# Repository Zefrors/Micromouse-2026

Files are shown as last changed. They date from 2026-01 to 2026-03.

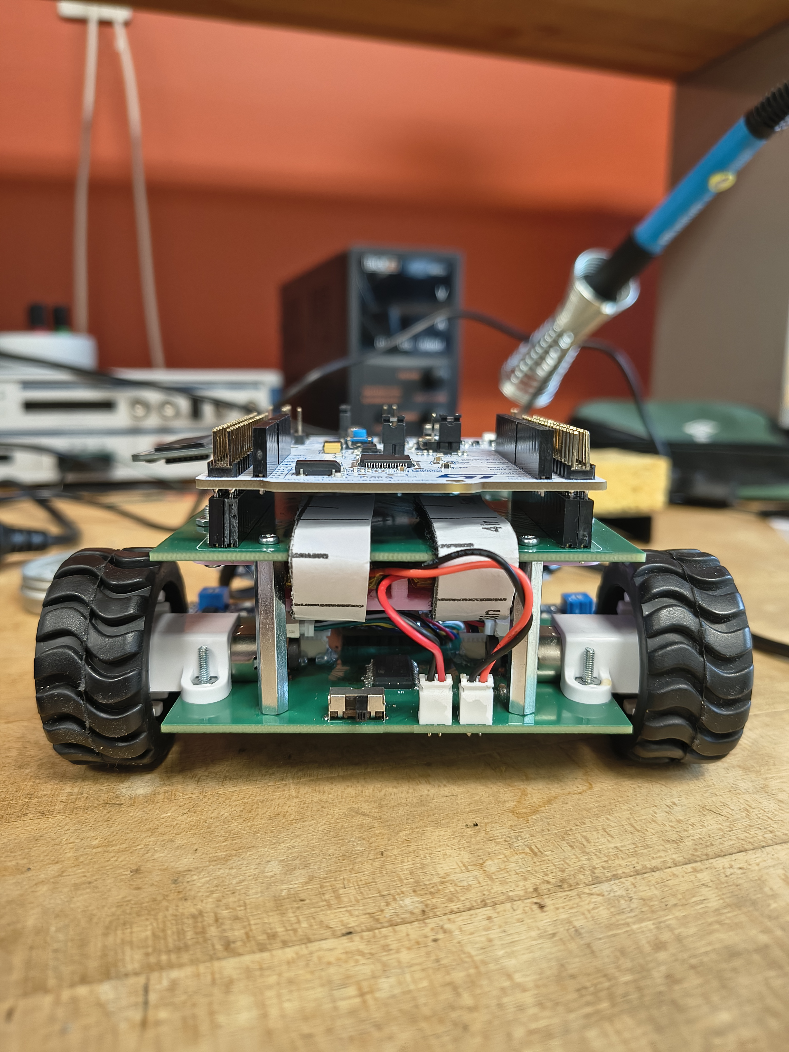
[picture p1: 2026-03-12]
pic/IMG_20260312_125618599_HDR.jpg

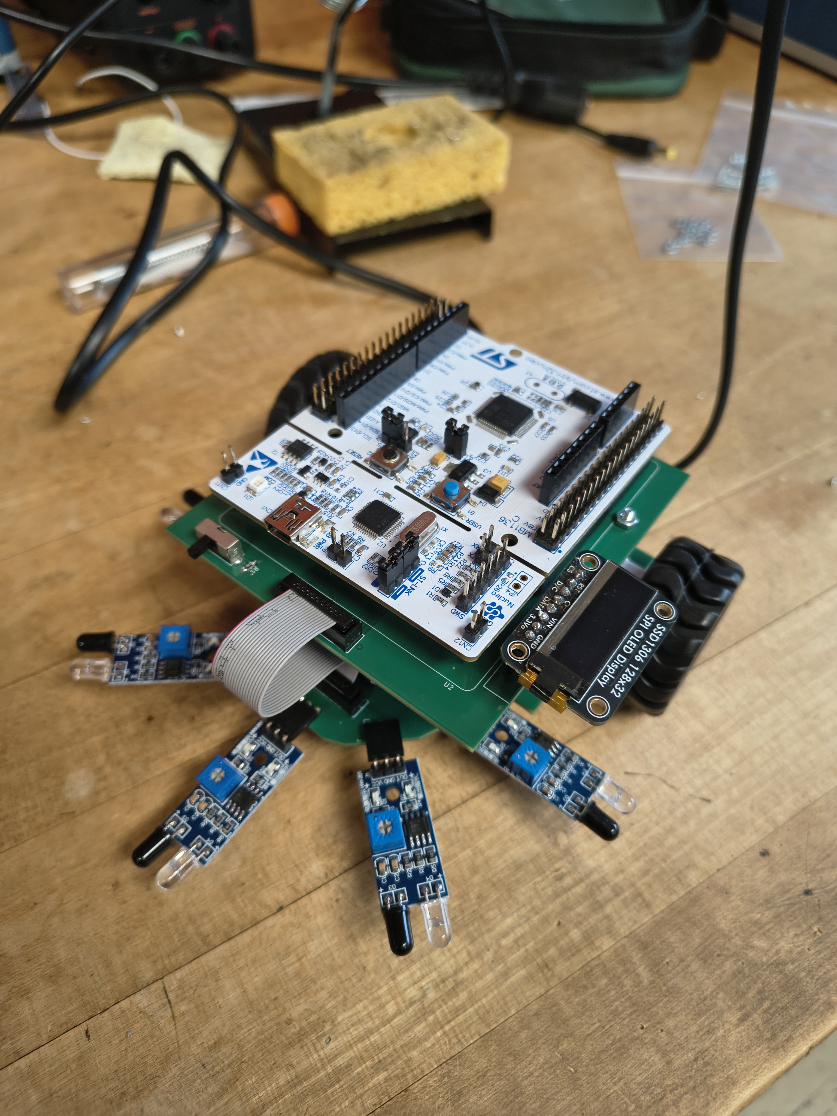
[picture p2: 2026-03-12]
pic/IMG_20260312_125603022_HDR.jpg

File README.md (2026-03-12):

# Temple IEEE Micromouse 2026
Competing at IEEE SAC R1 & R2! https://attend.ieee.org/sac-2026/ on 3/20/26

IMG_20260312_125613744_HDR
IMG_20260312_125603022_HDR
IMG_20260312_125618599_HDR

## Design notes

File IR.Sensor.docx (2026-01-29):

IR Sensor and Module

IR Sensor Module | How IR Sensor Module Works » ElectroDuino (https://www.electroduino.com/what-is-ir-sensor-module-how-ir-sensor-module-works/)

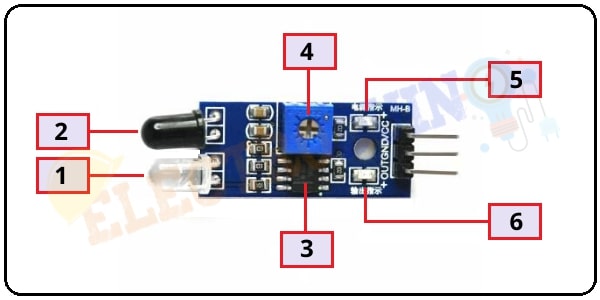
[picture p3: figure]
IR-Sensor-Module-Hardware-Overview IR Sensor Module | How IR Sensor Module Works

1. Infrared LED or IR Transmitter:

2. Photodiode Receiver or IR Receiver:

4. Variable Resistor (Trim pot)

- This variable resistor is a 10k preset. It is used to set the range of operation. Rotate the preset knob to adjust the detection distance, the effective operation range 2-10 cm. If the preset knob rotated clockwise, the detection range will be increased. If it rotated counterclockwise, the detection range will be decreased.

- Could be used for long/short distance reading

- IE When short distance sensor goes off we know the wall is close

5. Power LED:

- LED that indicates the IR Sensor power supply is on or off

6. Output LED:

- When infrared reflected back to the IR receiver and the sensor detects an obstacle, the green LED lights up. So, the Green LED use to indicate the sensor senses an obstacle.

Circuit

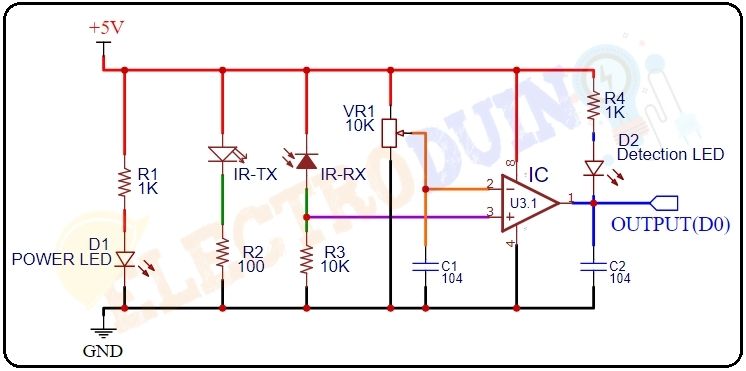
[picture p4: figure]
How-to-make-IR-Sensor-Module-Circuit-Diagram IR Sensor Module | How IR Sensor Module Works

Buy Link (https://www.amazon.com/EC-Buying-Infrared-Obstacle-Avoidance/dp/B0CWKWWKYL?adgrpid=1330409636736144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)

Intensity = 1/d^2

Calibration

Way to protect sensors if crash happens

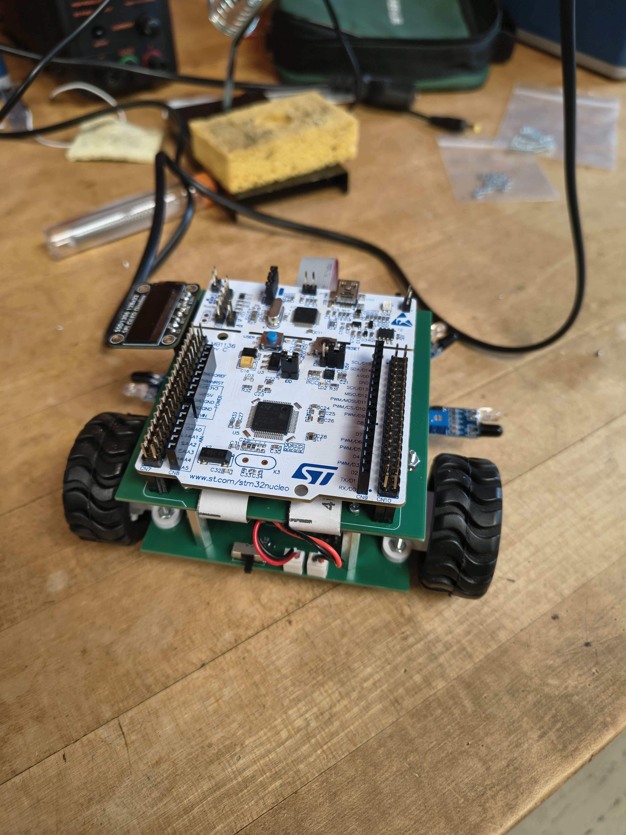
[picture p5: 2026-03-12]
pic/IMG_20260312_125607477_HDR.jpg

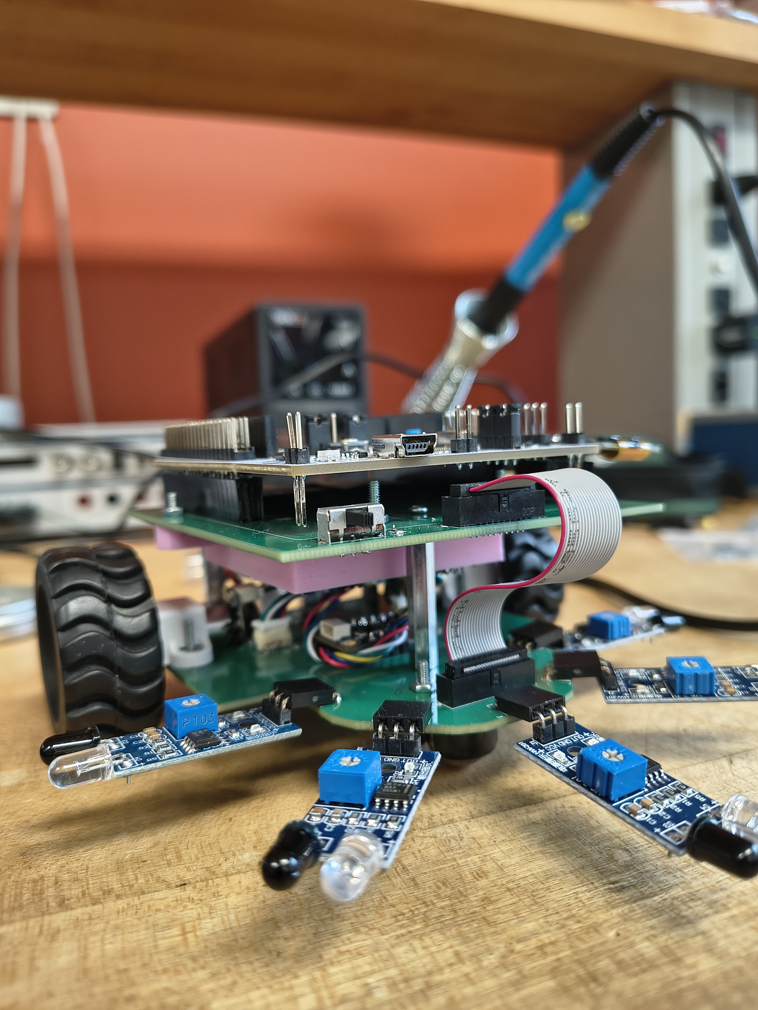
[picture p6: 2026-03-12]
pic/IMG_20260312_125613744_HDR.jpg

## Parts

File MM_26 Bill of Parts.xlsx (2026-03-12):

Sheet: Sheet1
Part | Quantity | Quantity Extra | Unit Price | Part Number | Link | Description | Total Price | URL
Motor | 2 |  | $20.95 | 2378 | https://www.pololu.com/product/2378 | Small brushed motor | $41.90 | https://www.pololu.com/product/2378
Motor Encoder Pair | 1 |  | $7.95 | 4760 | https://www.pololu.com/product/4760 | Encoder pair for motors ; connect at back | $7.95 | https://www.pololu.com/product/4760
Wheels | 1 |  | $8.95 | 1090 | https://www.pololu.com/product/1090 | attach to motor bracket | $8.95 | https://www.pololu.com/product/1090
IR Sensor Module | 5 | 5 | $0.88 |  | https://amazon.com/dp/B07W97H2WS |  | $8.79 | https://amazon.com/dp/B07W97H2WS
Dual H-Bridge | 1 |  | $7.69 | 497-1390-5-ND | https://www.digikey.com/en/products/detail/stmicroelectronics/L293DD/585913 | IC dual-H bridge | $7.69 | https://www.digikey.com/en/products/detail/stmicroelectronics/L293DD/585913
IMU | 1 |  | $19.95 | 4502 | https://www.adafruit.com/product/4502 | Gryo + Accel | $19.95 | https://www.adafruit.com/product/4502
STM32 Nucleo L476RG | 1 |  | $14.53 |  | https://www.st.com/en/evaluation-tools/nucleo-l476rg.html#st_all-features_sec-nav-tab | STM32 Nucleo Board | $14.53 | https://www.st.com/en/evaluation-tools/nucleo-l476rg.html#st_all-features_sec-nav-tab
Caster Wheel |  | Decide based on height |  |  |  |  |  | https://www.pololu.com/category/45/pololu-ball-casters
OLED Screen | 1 |  | $17.50 | 661 | https://www.adafruit.com/product/661 | Display |  | https://www.adafruit.com/product/661
Voltage Regulator | 1 |  | $0.24 | AZ1117IH-3.3TRG1DICT-ND | https://www.digikey.com/en/products/detail/diodes-incorporated/AZ1117IH-3-3TRG1/5699672 | 3V3 LDO Regulator |  | https://www.digikey.com/en/products/detail/diodes-incorporated/AZ1117IH-3-3TRG1/5699672
Battery Connector | 2 |  | $0.10 | 455-1704-ND | https://www.digikey.com/en/products/detail/jst-sales-america-inc/B2B-PH-K-S-LF-SN/926611 | 2mm JST Connector |  | https://www.digikey.com/en/products/detail/jst-sales-america-inc/B2B-PH-K-S-LF-SN/926611
Slide Switch | 2 | 1 | $0.72 | EG1906-ND | https://www.digikey.com/en/products/detail/e-switch/EG1213/101735 | Switch |  | https://www.digikey.com/en/products/detail/e-switch/EG1213/101735
JST SH Connector | 2 |  | $0.67 | 455-BM06B-SRSS-TBCT-ND | www.digikey.com/en/products/detail/jst-sales-america-inc/BM06B-SRSS-TB/926698 | Motor to Board |  | www.digikey.com/en/products/detail/jst-sales-america-inc/BM06B-SRSS-TB/926698
Motor Cable | Decide Length |  |  |  |  |  |  | https://www.pololu.com/category/277/6-pin-jst-sh-style-cables-for-micro-metal-gearmotor-encoders
Right Angle Pin Header | 5 |  | $0.52 | 2703 |  | For IR Sensor Module |  | https://www.pololu.com/product/2703
Motor Bracket | 1 |  | $4.95 | 1089 | https://www.pololu.com/category/161/brackets-for-micro-metal-gearmotors
Resistor | 1 | 9 | $0.01 |  | https://www.digikey.com/en/products/detail/yageo/RC0805JR-0710KL/728241
100nF |  |  |  | 399-C0805C104K5RACTUCT-ND | https://www.digikey.com/en/products/detail/kemet/C0805C104K5RACTU/411169
4.7uF |  |  |  | 1276-1244-1-ND | https://www.digikey.com/en/products/detail/samsung-electro-mechanics/CL21A475KAQNNNE/3886902
10uF |  |  |  | 1276-2872-1-ND | https://www.digikey.com/en/products/detail/samsung-electro-mechanics/CL21B106KOQNNNE/3888530
22uF |  |  |  | 1276-CL21A226MAYNNNECT-ND | https://www.digikey.com/en/products/detail/samsung-electro-mechanics/CL21A226MAYNNNE/10479857
IDC Cable Header |  |  |  |  | https://www.digikey.com/en/products/detail/cnc-tech/3220-20-0100-00/3883663
Cable Short |  |  |  |  | https://www.digikey.com/en/products/detail/samtec-inc/FFSD-10-D-02-00-01-N/1106582
Cable Long |  |  |  |  | https://www.digikey.com/en/products/detail/samtec-inc/FFSD-10-D-03-00-01-N/2651117

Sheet: receipts
 | Cost | Receipt | Description
DIGIKEY 1 | 50.08 |  | Materials to connect top and bottom board
DIGIKEY 2 | 38.56 |  | Parts on boards
ADAFRUIT | 55.93 |  | Gyroscope + OLED
JLC | 71.43 |  | PCBs
POLOLU | 113.18 |  | Motors, Mechanical Assembly Parts
AMAZON | 19.9 |  | Batteries
TOTAL | 349.08

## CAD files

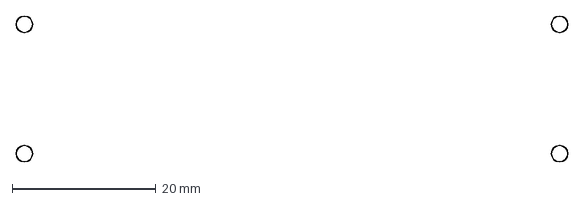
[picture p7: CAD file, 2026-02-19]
MM26/edge_cuts/mm26_bottom_motor_holes.dxf
76.8 x 20.3 mm

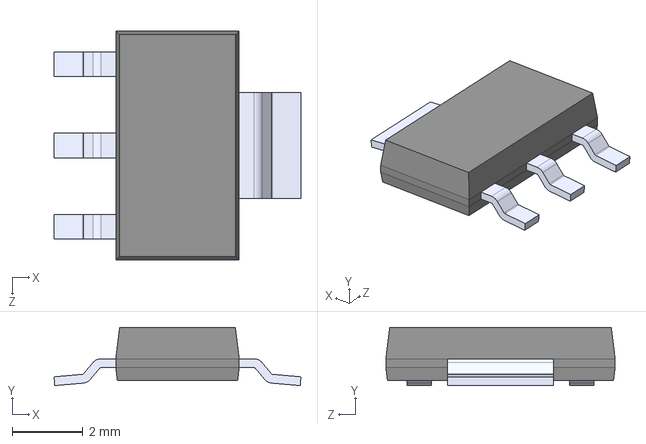
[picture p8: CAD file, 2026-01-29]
MM26/parts/AZ1117IH_3_3TRG1/AZ1117IH-3.3TRG1.step
7.00 x 1.65 x 6.50 mm

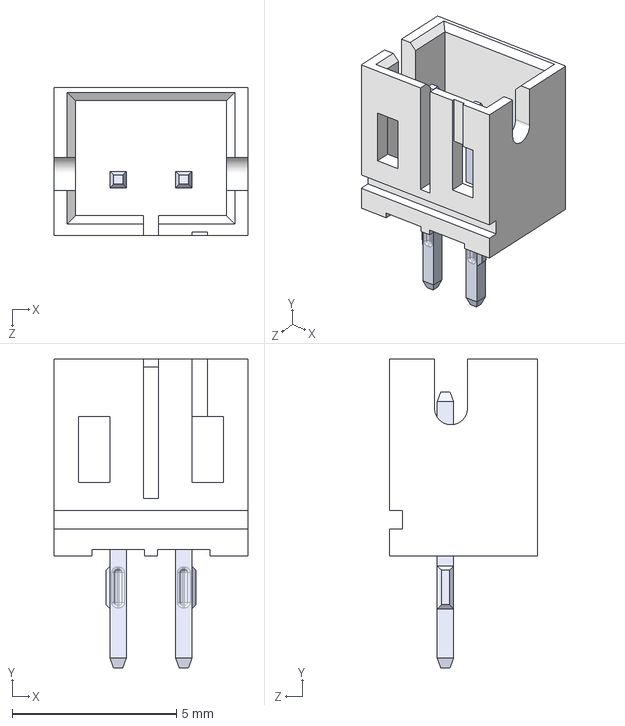
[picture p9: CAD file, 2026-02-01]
MM26/parts/B2B_PH_K_S/B2B-PH-K-S.step
5.90 x 9.40 x 4.50 mm

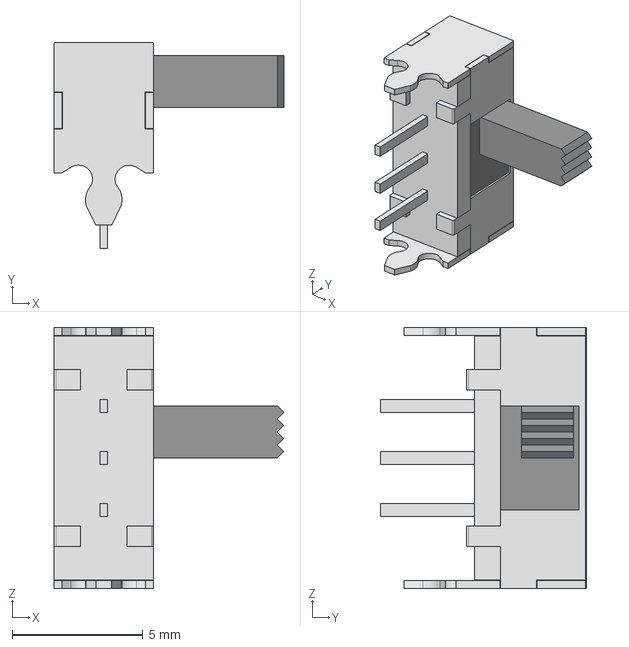
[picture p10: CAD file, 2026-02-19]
MM26/parts/EG1213/EG1213.step
8.80 x 7.90 x 10.00 mm

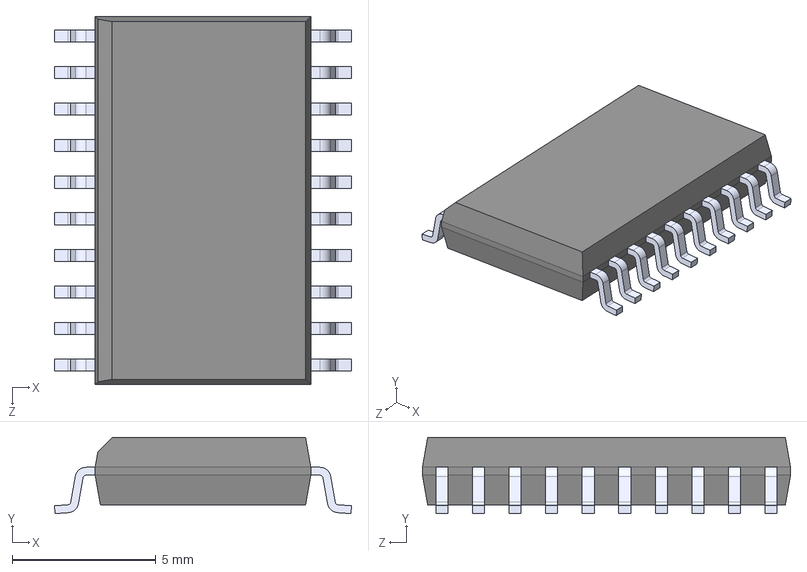
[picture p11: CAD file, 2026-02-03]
MM26/parts/L293DD/L293DD.step
10.3 x 2.65 x 12.8 mm

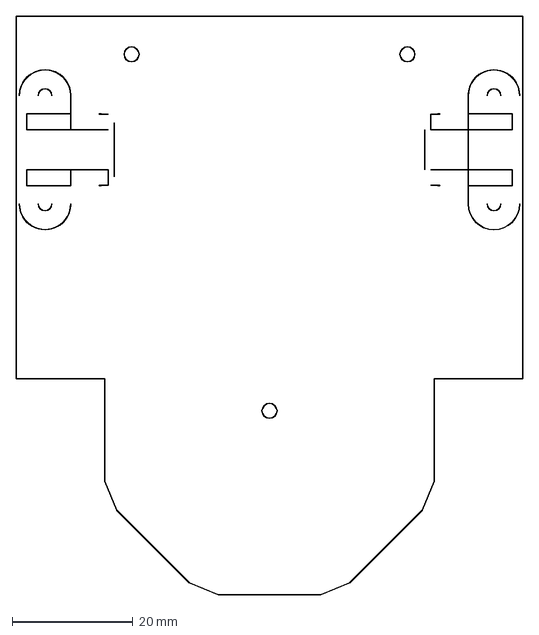
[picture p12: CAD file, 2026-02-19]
MM26/edge_cuts/mm26_bottom_motor.dxf
84.0 x 96.0 mm

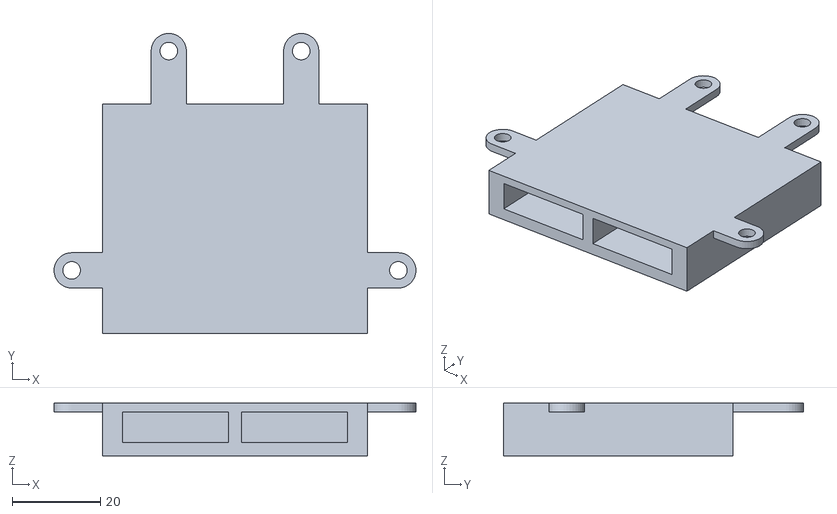
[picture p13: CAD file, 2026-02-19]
MM26/edge_cuts/mm26_horizontal_holder.stl
82.0 x 68.0 x 12.0

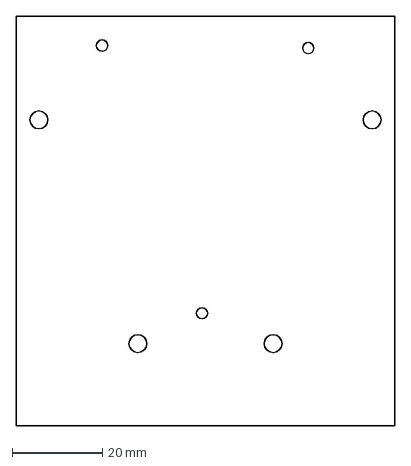
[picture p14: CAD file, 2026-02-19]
MM26/edge_cuts/mm26_top.dxf
84.0 x 91.0 mm

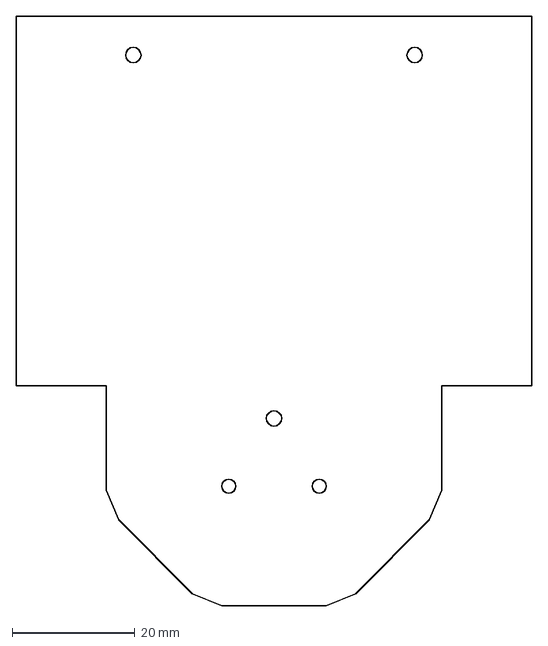
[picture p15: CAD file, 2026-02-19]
MM26/edge_cuts/bottom_no_motor.dxf
84.0 x 96.0 mm

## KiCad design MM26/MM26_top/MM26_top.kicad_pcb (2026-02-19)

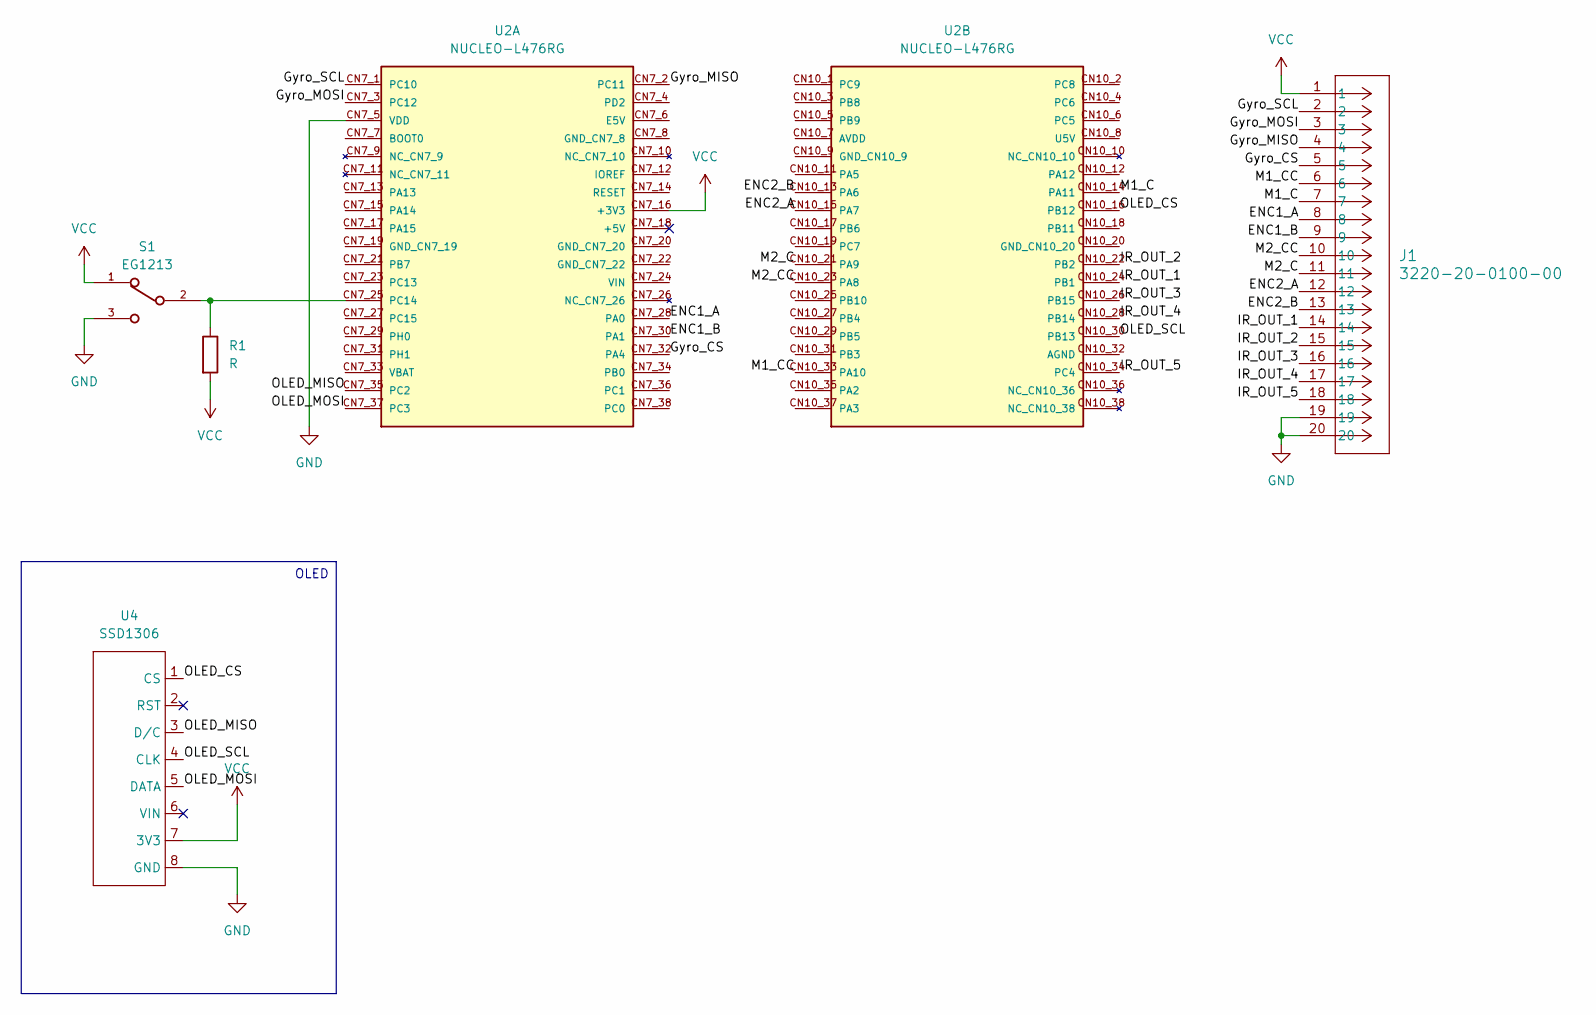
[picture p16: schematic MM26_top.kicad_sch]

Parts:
J1: 3220-20-0100-00; CONN20_3220-20_CNC
R1: R; R_0805_2012Metric_Pad1.20x1.40mm_HandSolder
S1: EG1213; SW_EG1213
U2: NUCLEO-L476RG; MODULE_NUCLEO-L476RG; PARTREV 15
U4: SSD1306

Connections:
/ENC1_A: J1.8, U2.CN7_28 (PA0)
/ENC1_B: J1.9, U2.CN7_30 (PA1)
/ENC2_A: J1.12, U2.CN10_15 (PA7)
/ENC2_B: J1.13, U2.CN10_13 (PA6)
/Gyro_CS: J1.5, U2.CN7_32 (PA4)
/Gyro_MISO: J1.4, U2.CN7_2 (PC11)
/Gyro_MOSI: J1.3, U2.CN7_3 (PC12)
/Gyro_SCL: J1.2, U2.CN7_1 (PC10)
/IR_OUT_1: J1.14, U2.CN10_24 (PB1)
/IR_OUT_2: J1.15, U2.CN10_22 (PB2)
/IR_OUT_3: J1.16, U2.CN10_26 (PB15)
/IR_OUT_4: J1.17, U2.CN10_28 (PB14)
/IR_OUT_5: J1.18, U2.CN10_34 (PC4)
/M1_C: J1.7, U2.CN10_14 (PA11)
/M1_CC: J1.6, U2.CN10_33 (PA10)
/M2_C: J1.11, U2.CN10_21 (PA9)
/M2_CC: J1.10, U2.CN10_23 (PA8)
/OLED_CS: U2.CN10_16 (PB12), U4.1 (CS)
/OLED_MISO: U2.CN7_35 (PC2), U4.3 (D/C)
/OLED_MOSI: U2.CN7_37 (PC3), U4.5 (DATA)
/OLED_SCL: U2.CN10_30 (PB13), U4.4 (CLK)
GND: J1.19, J1.20, S1.3, U2.CN7_5 (VDD), U4.8 (GND)
unnamed: R1.1, S1.2, U2.CN7_25 (PC14)
VCC: J1.1, R1.2, S1.1, U2.CN7_16 (+3V3), U4.7 (3V3)

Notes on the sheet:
OLED

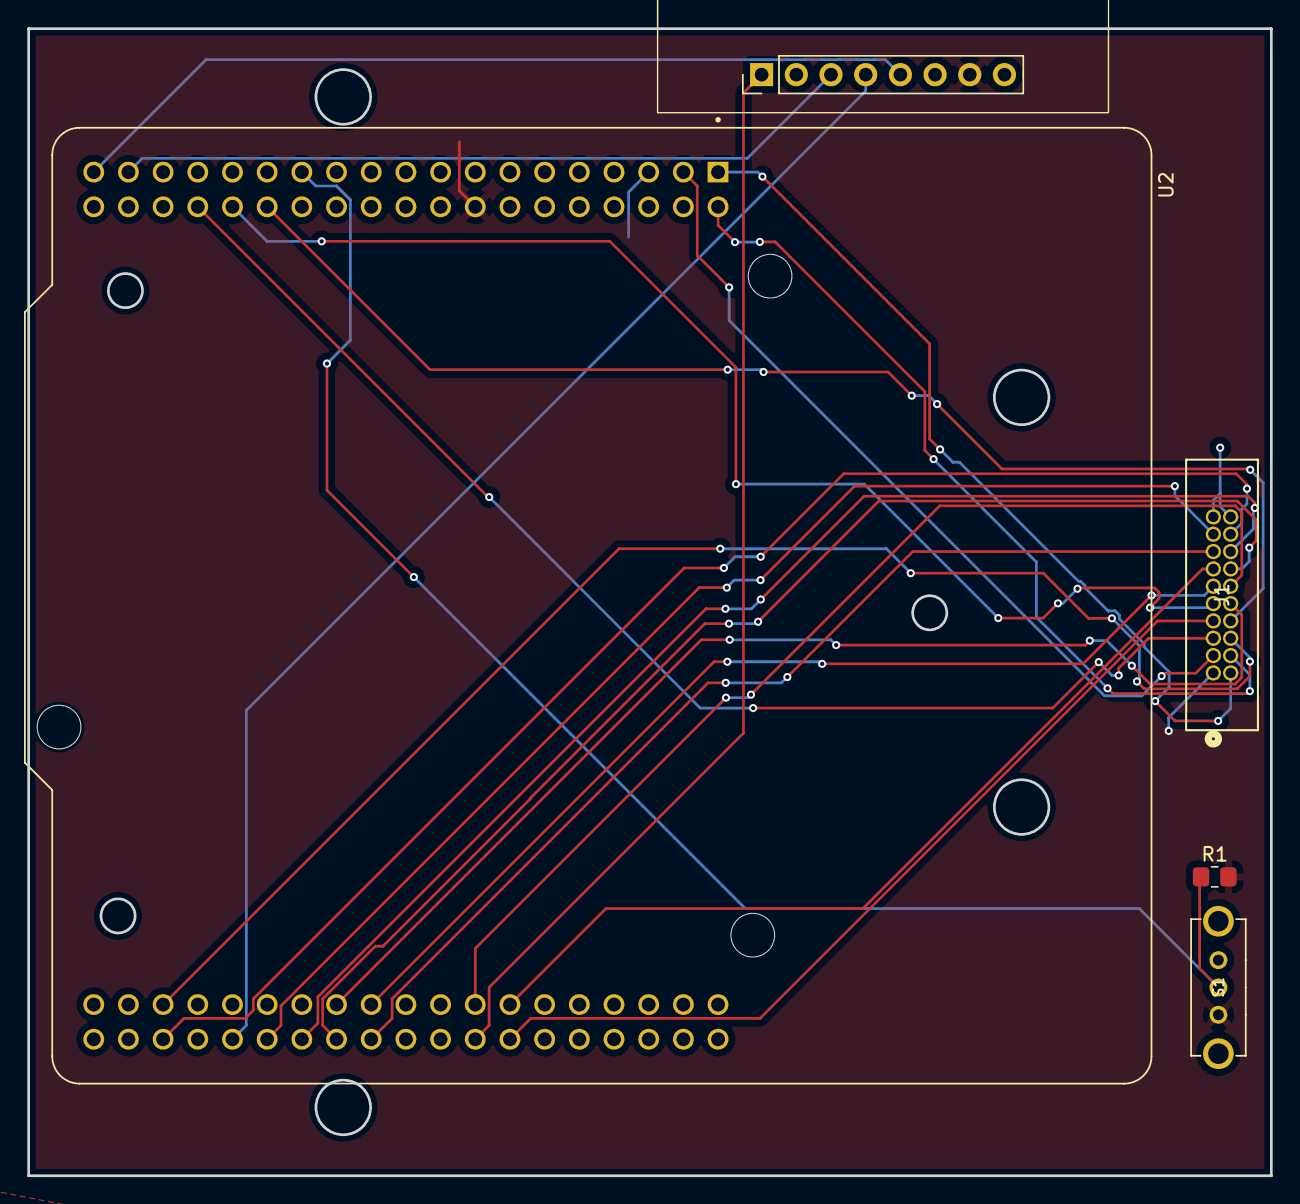
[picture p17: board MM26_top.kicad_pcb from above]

Board: 2 copper layers, 91.0 x 84.0 mm, 5 parts (0 on the bottom side), 24 nets.

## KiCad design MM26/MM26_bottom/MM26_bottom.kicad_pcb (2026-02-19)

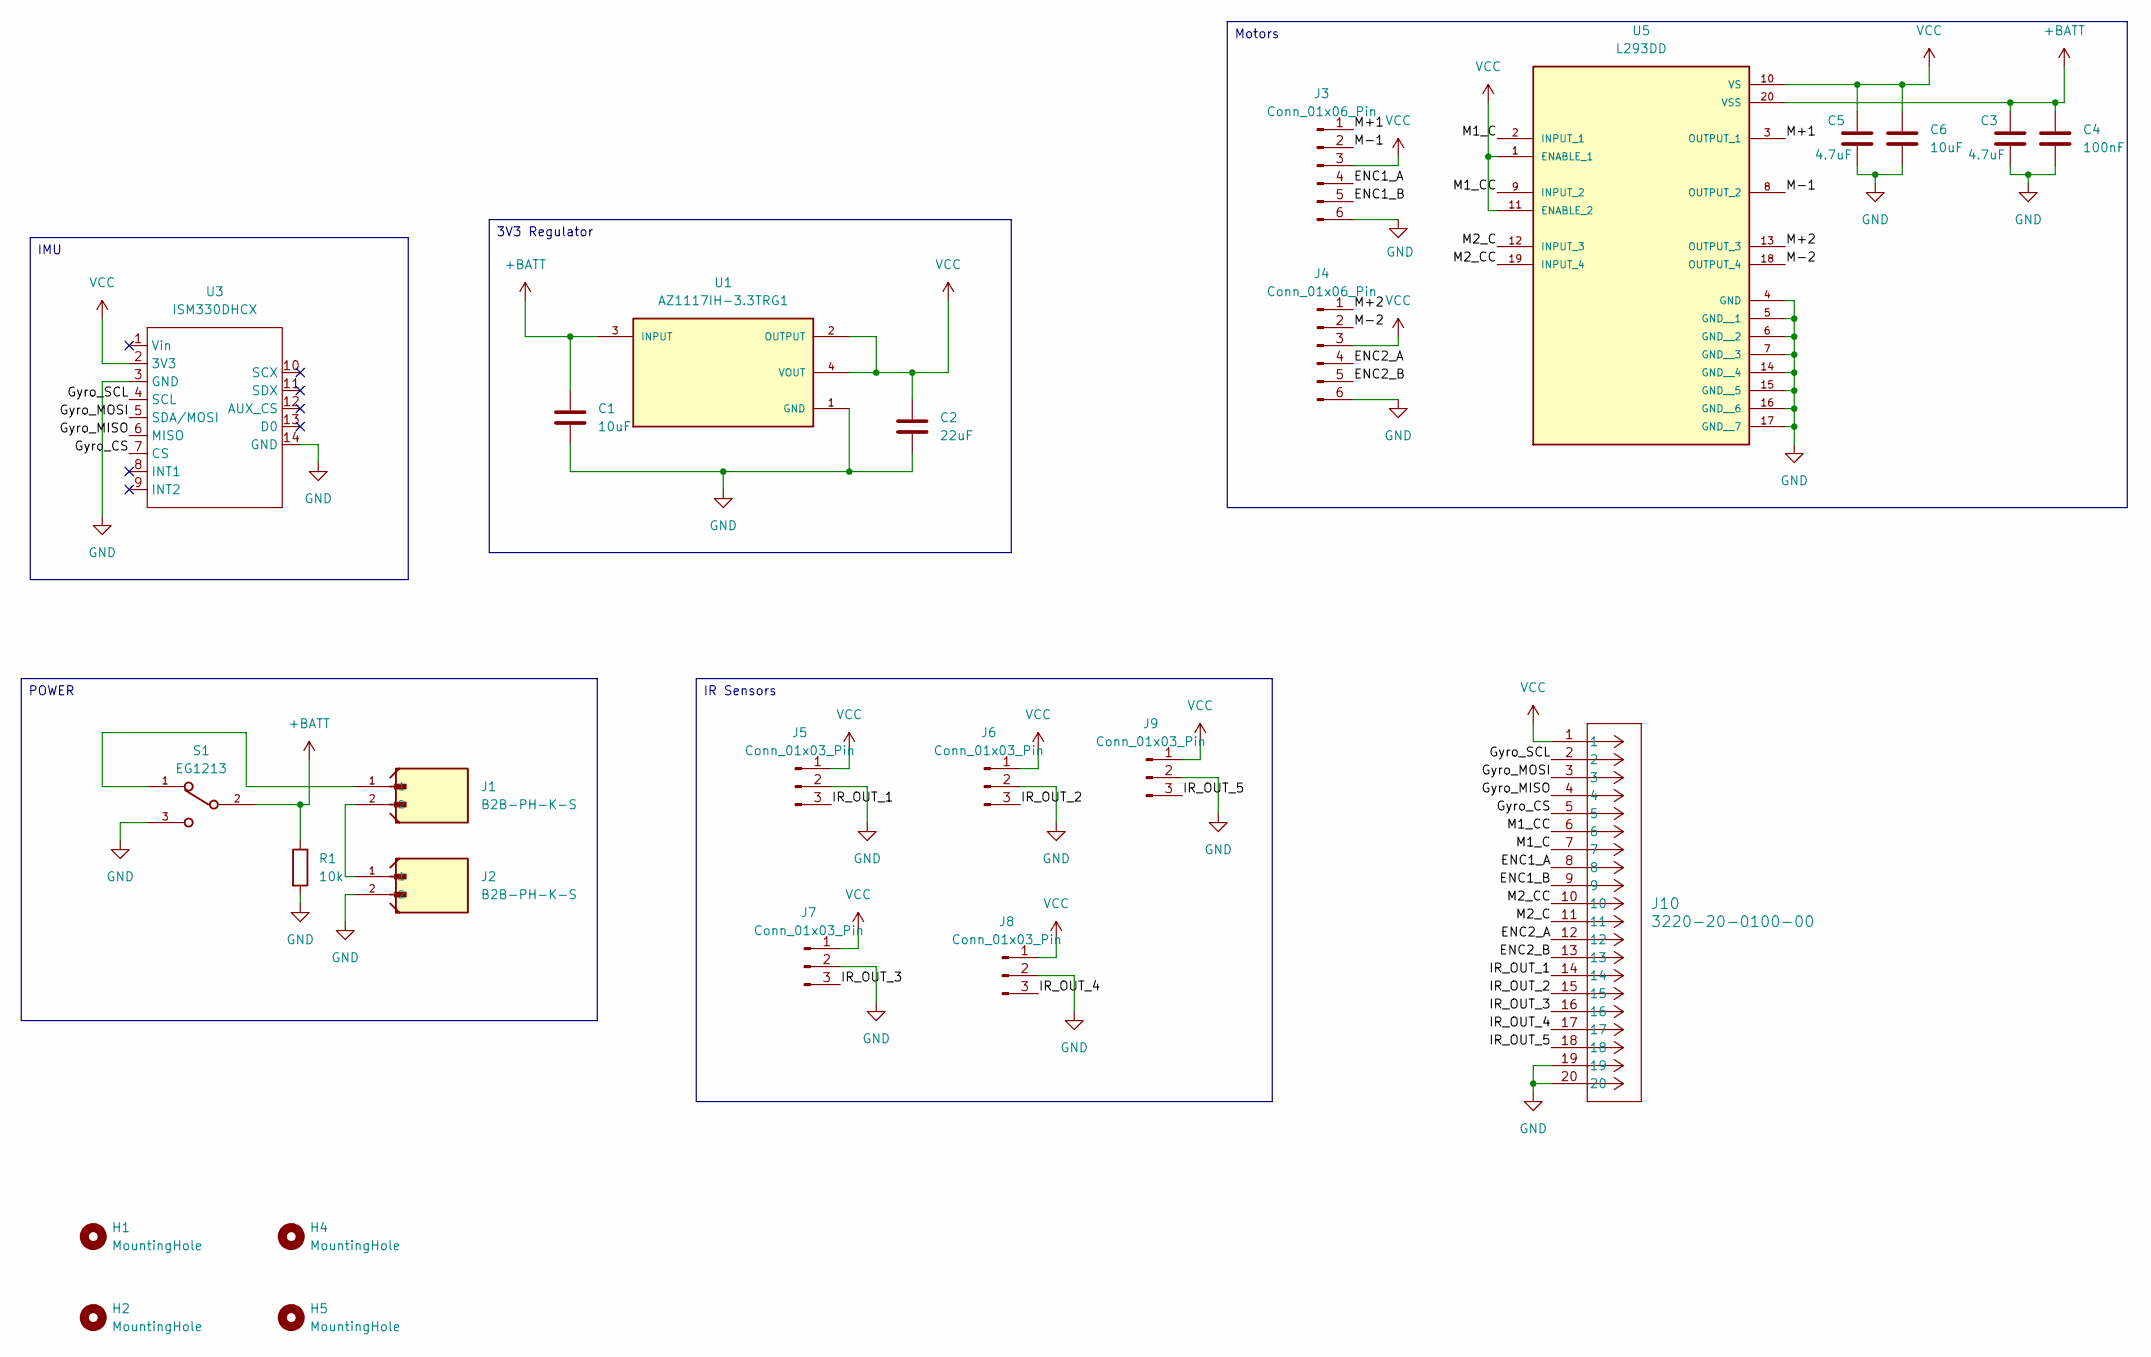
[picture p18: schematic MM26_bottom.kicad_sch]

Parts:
C1, C6: 10uF; C_0805_2012Metric_Pad1.18x1.45mm_HandSolder
C2: 22uF; C_0805_2012Metric_Pad1.18x1.45mm_HandSolder
C3, C5: 4.7uF; C_0805_2012Metric_Pad1.18x1.45mm_HandSolder
C4: 100nF; C_0805_2012Metric_Pad1.18x1.45mm_HandSolder
H1, H2, H4, H5: MountingHole; MountingHole_2.5mm
J1, J2: B2B-PH-K-S; JST_B2B-PH-K-S
J3, J4: Conn_01x06_Pin; JST_SH_BM06B-SRSS-TB_1x06-1MP_P1.00mm_Vertical
J5, J6, J7, J8, J9: Conn_01x03_Pin; PinSocket_1x03_P2.54mm_Horizontal
J10: 3220-20-0100-00; CONN20_3220-20_CNC
R1: 10k; R_0805_2012Metric_Pad1.20x1.40mm_HandSolder
S1: EG1213; SW_EG1213
U1: AZ1117IH-3.3TRG1; SOT230P700X185-4N; PARTREV 2-2
U3: ISM330DHCX
U5: L293DD; SOIC127P1032X265-20N; PARTREV N/A

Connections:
+BATT: C1.1, C3.1, C4.1, R1.1, S1.2, U1.3 (INPUT), U5.20 (VSS)
/ENC1_A: J3.4, J10.8
/ENC1_B: J3.5, J10.9
/ENC2_A: J4.4, J10.12
/ENC2_B: J4.5, J10.13
/Gyro_CS: J10.5, U3.7 (CS)
/Gyro_MISO: J10.4, U3.6 (MISO)
/Gyro_MOSI: J10.3, U3.5 (SDA/MOSI)
/Gyro_SCL: J10.2, U3.4 (SCL)
/IR_OUT_1: J5.3, J10.14
/IR_OUT_2: J6.3, J10.15
/IR_OUT_3: J7.3, J10.16
/IR_OUT_4: J8.3, J10.17
/IR_OUT_5: J9.3, J10.18
/M1_C: J10.7, U5.2 (INPUT_1)
/M1_CC: J10.6, U5.9 (INPUT_2)
/M2_C: J10.11, U5.12 (INPUT_3)
/M2_CC: J10.10, U5.19 (INPUT_4)
/M+1: J3.1, U5.3 (OUTPUT_1)
/M+2: J4.1, U5.13 (OUTPUT_3)
/M-1: J3.2, U5.8 (OUTPUT_2)
/M-2: J4.2, U5.18 (OUTPUT_4)
GND: C1.2, C2.2, C3.2, C4.2, C5.2, C6.2, J2.2, J3.6, J4.6, J5.2, J6.2, J7.2, J8.2, J9.2, J10.19, J10.20, R1.2, S1.3, U1.1 (GND), U3.3 (GND), U3.14 (GND), U5.4 (GND), U5.5 (GND__1), U5.6 (GND__2), U5.7 (GND__3), U5.14 (GND__4), U5.15 (GND__5), U5.16 (GND__6), U5.17 (GND__7)
unnamed: J1.1, S1.1
unnamed: J1.2, J2.1
VCC: C2.1, C5.1, C6.1, J3.3, J4.3, J5.1, J6.1, J7.1, J8.1, J9.1, J10.1, U1.2 (OUTPUT), U1.4 (VOUT), U3.2 (3V3), U5.1 (ENABLE_1), U5.10 (VS), U5.11 (ENABLE_2)

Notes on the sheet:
IMU
IR Sensors
Motors
POWER
3V3 Regulator

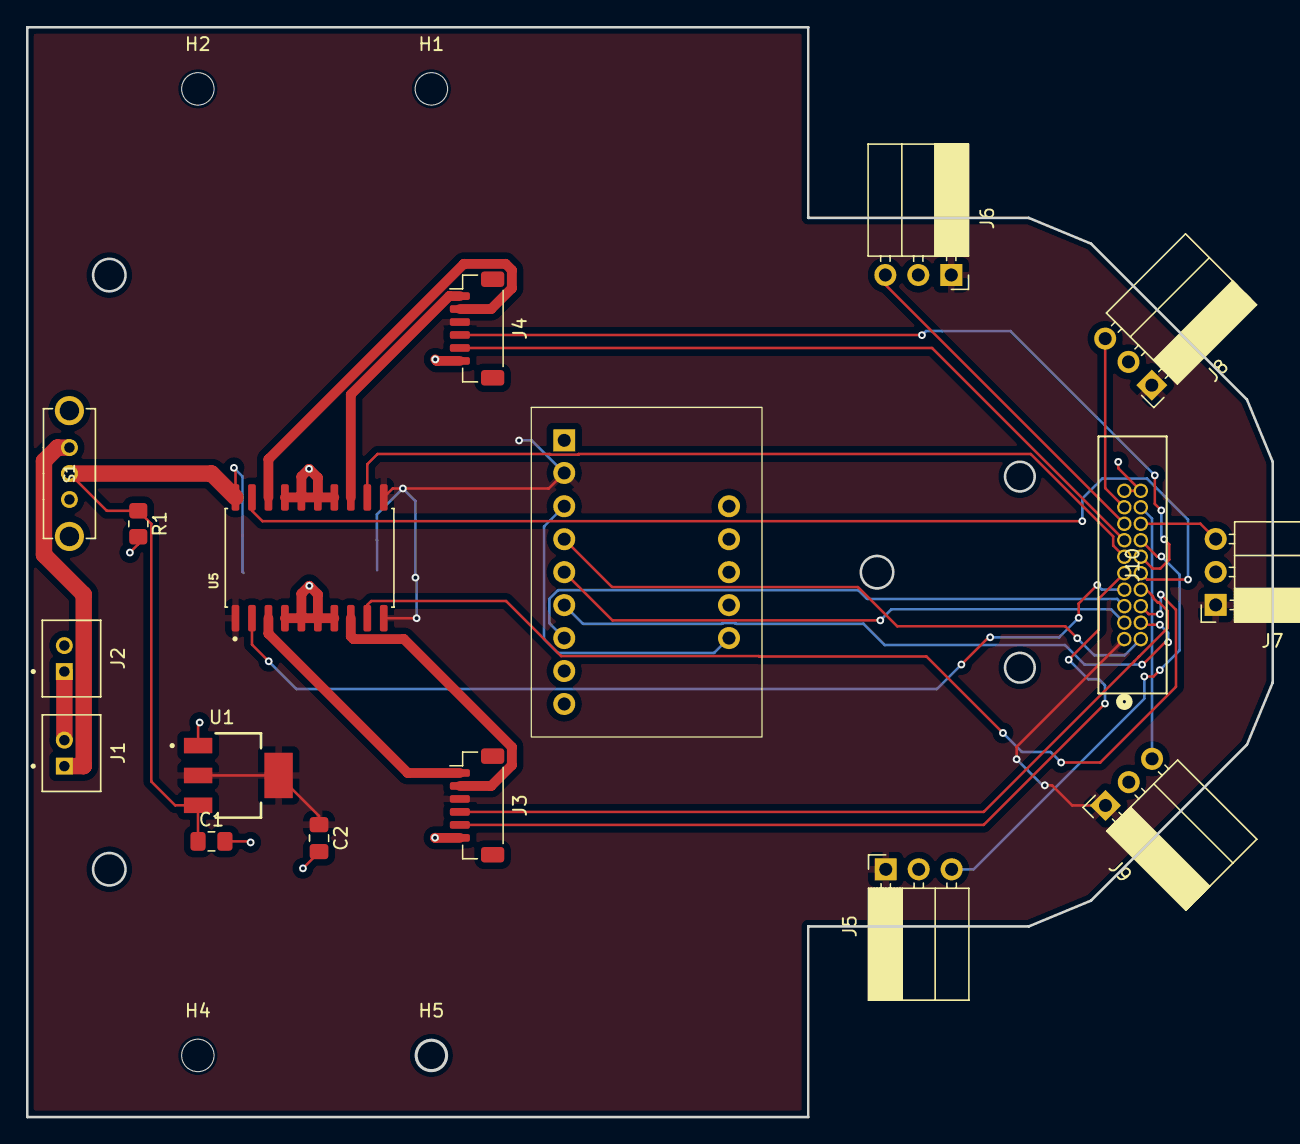
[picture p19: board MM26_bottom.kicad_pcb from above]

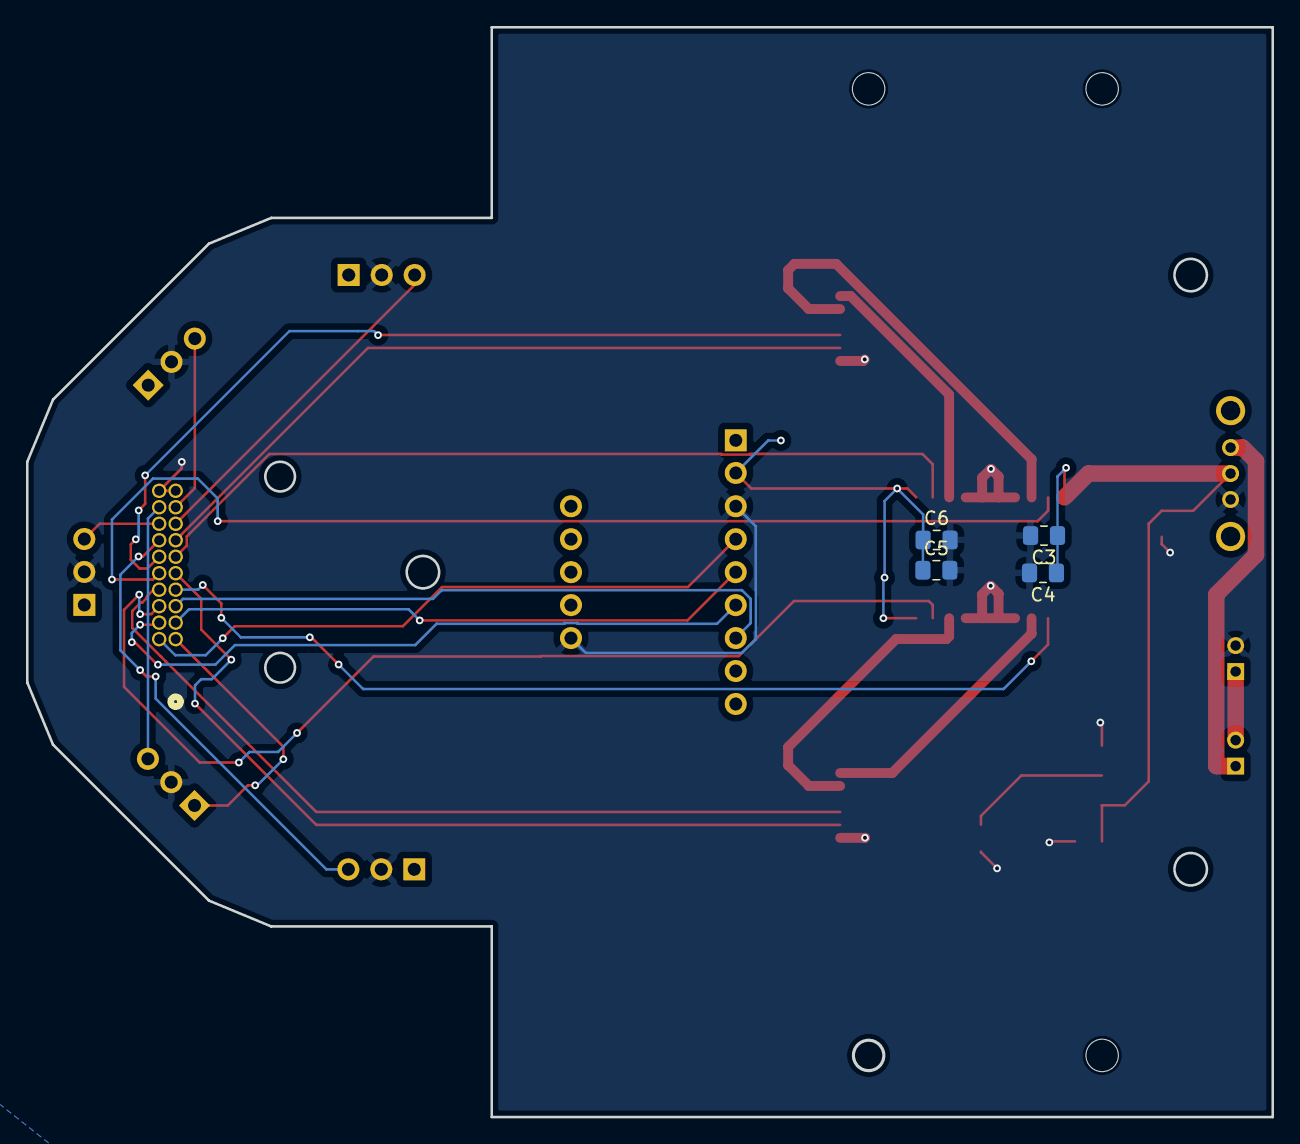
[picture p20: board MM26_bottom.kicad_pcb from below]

Board: 2 copper layers, 96.0 x 84.0 mm, 25 parts (4 on the bottom side), 26 nets.

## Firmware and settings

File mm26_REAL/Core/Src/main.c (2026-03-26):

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
/* Includes ------------------------------------------------------------------*/
#include "main.h"

/* USER CODE BEGIN Includes */
#include "custom_motion_sensors.h"
#include "ssd1306.h"
#include "ssd1306_fonts.h"
#include "itoa.h"
#include "ftoa.h"
#include "motors.h"
#include "delay.h"
#include "irs.h"
#include "motion_gc.h"
#include "motion_fx.h"
#include "motion_ac.h"
#include "solver.h"
#include "systick.h"
/* USER CODE END Includes */

/* USER CODE BEGIN PD */
#define MFX_STR_LENG 35
#define STATE_SIZE (size_t)(2450)
#define ENABLE_6X 1
#define SAMPLE_FREQUENCY 416.0f
#define ACCEL_SENSITIVITY 0.488f
#define GYRO_SENSITIVITY 70.0f
/* USER CODE END PD */

ADC_HandleTypeDef hadc1;
DMA_HandleTypeDef hdma_adc1;
CRC_HandleTypeDef hcrc;
SPI_HandleTypeDef hspi2;
TIM_HandleTypeDef htim1;
TIM_HandleTypeDef htim2;
TIM_HandleTypeDef htim3;
TIM_HandleTypeDef htim4;
UART_HandleTypeDef huart2;
DMA_HandleTypeDef hdma_usart2_rx;
void SystemClock_Config(void);
static void MX_GPIO_Init(void);
static void MX_DMA_Init(void);
static void MX_CRC_Init(void);
static void MX_USART2_UART_Init(void);
static void MX_SPI2_Init(void);
static void MX_TIM1_Init(void);
static void MX_TIM2_Init(void);
static void MX_TIM3_Init(void);
static void MX_ADC1_Init(void);
static void MX_TIM4_Init(void);
/* USER CODE BEGIN 0 */
CUSTOM_MOTION_SENSOR_Axes_t gyr_value;
CUSTOM_MOTION_SENSOR_Axes_t acc_value;
CUSTOM_MOTION_SENSOR_AxesRaw_t gyr_raw;
CUSTOM_MOTION_SENSOR_AxesRaw_t acc_raw;
int16_t left_counts = 0;
int16_t right_counts = 0;
char ret;
char salutations[] = "HI!";
char xline[] = "VALUE: ";
char yline[] = "ENC COUNTS: ";
char zline[] = "RIGHT: ";
char empty[] = "                ";
char buffer[20];
int32_t x_vals[1000];
uint16_t x_cnt;
int32_t x_avg;
int32_t x_sum;
double x_pos = 0;
uint16_t motor_right_cnt;
uint16_t IR_VALUE;
uint16_t debug;
// motion gc
MGC_knobs_t knobs;
MGC_output_t start_gyro_bias;
float sample_freq = SAMPLE_FREQUENCY;
volatile float gyro_cal_x, gyro_cal_y, gyro_cal_z;
MGC_input_t data_in;
MGC_output_t data_out;
int bias_update = 0;
// other stuff
int16_t error;
int16_t enc;
//motion fx
static uint8_t mfxstate[STATE_SIZE];
MFX_knobs_t iKnobs;
// motion ac
MAC_knobs_t acc_knobs;
MAC_output_t start_acc_bias;
volatile float acc_cal_x, acc_cal_y, acc_cal_z;
MAC_input_t acc_data_in;
MAC_output_t acc_data_out;
uint8_t acc_bias_update = 0;
uint32_t CurrentTime, LastTime;
unsigned int calData[50];
MFX_input_t mfx_data_in;
MFX_output_t mfx_data_out;
float *q; /* Quaternion pointer to either to Game Rotation or Rotation vector (4 length) */
int32_t ret1, ret2, ret3;
int calibrating = 1;
float straight_angle;
float str_sum;
int n_str;
int is_cal_str;
uint16_t ir_f, ir_l, ir_r;
/* USER CODE END 0 */

/**
  * @brief  The application entry point.
  * @retval int
  */
int main(void)
{

  /* MCU Configuration--------------------------------------------------------*/

  /* Reset of all peripherals, Initializes the Flash interface and the Systick. */
  HAL_Init();

  /* Configure the system clock */
  SystemClock_Config();

  /* Initialize all configured peripherals */
  MX_GPIO_Init();
  MX_DMA_Init();
  MX_CRC_Init();
  MX_USART2_UART_Init();
  MX_SPI2_Init();
  MX_TIM1_Init();
  MX_TIM2_Init();
  MX_TIM3_Init();
  MX_ADC1_Init();
  MX_TIM4_Init();
  /* USER CODE BEGIN 2 */
  ssd1306_Init();
  CUSTOM_MOTION_SENSOR_Init(CUSTOM_ISM330DHCX_0, MOTION_GYRO | MOTION_ACCELERO);
  CUSTOM_MOTION_SENSOR_SetOutputDataRate(CUSTOM_ISM330DHCX_0, MOTION_GYRO | MOTION_ACCELERO, (float_t) 416);
  CUSTOM_MOTION_SENSOR_SetFullScale(CUSTOM_ISM330DHCX_0, MOTION_ACCELERO, 16);
  CUSTOM_MOTION_SENSOR_SetFullScale(CUSTOM_ISM330DHCX_0, MOTION_GYRO, 2000);
  CUSTOM_MOTION_SENSOR_Enable(CUSTOM_ISM330DHCX_0, MOTION_GYRO | MOTION_ACCELERO);
  HAL_TIM_Encoder_Start(&htim2, TIM_CHANNEL_ALL);
  HAL_TIM_Encoder_Start(&htim3, TIM_CHANNEL_ALL);
  // PWM SETUP
  HAL_TIM_PWM_Start(&htim1, TIM_CHANNEL_1);
  HAL_TIM_PWM_Start(&htim1, TIM_CHANNEL_2);
  HAL_TIM_PWM_Start(&htim1, TIM_CHANNEL_3);
  HAL_TIM_PWM_Start(&htim1, TIM_CHANNEL_4);
  HAL_TIM_Base_Start_IT(&htim4);
  __HAL_TIM_CLEAR_FLAG(&htim4, TIM_FLAG_UPDATE);
  Delay_Init();
  // GYRO INIT
  /*
  MotionGC_Initialize(MGC_MCU_STM32, &sample_freq);
  MotionGC_GetKnobs(&knobs);
  knobs.AccThr = 0.008f;
  knobs.GyroThr = 0.15;
  MotionGC_SetKnobs(&knobs);
  start_gyro_bias.GyroBiasX = 0;
  start_gyro_bias.GyroBiasY = 0;
  start_gyro_bias.GyroBiasZ = 0;
  MotionGC_SetCalParams(&start_gyro_bias);
  //sample_freq = SAMPLE_FREQUENCY;
  MotionGC_SetFrequency(&sample_freq);
  */
  // motion fx
  if (STATE_SIZE < MotionFX_GetStateSize())
  {
	  Error_Handler();
  }
  MotionFX_initialize(mfxstate);
  MotionFX_getKnobs(mfxstate, &iKnobs);
  iKnobs.gbias_gyro_th_sc = 0.01;
  iKnobs.gbias_acc_th_sc = 0.005;
  iKnobs.LMode = 1;
  MotionFX_setKnobs(mfxstate, &iKnobs);
  MotionFX_enable_6X(mfxstate, MFX_ENGINE_DISABLE);
  MotionFX_enable_9X(mfxstate, MFX_ENGINE_DISABLE);
  // motionac
  /*
  __HAL_RCC_CRC_CLK_ENABLE();
  MotionAC_Initialize(1);
  MotionAC_GetKnobs(&acc_knobs);
  acc_knobs.Sample_ms = sample_freq;
  (void)MotionAC_SetKnobs(&acc_knobs);
  */
//ssd1306_DrawPixel(1, 1, White);
  while(HAL_GPIO_ReadPin(GPIOC, GPIO_PIN_13)){} // wait for blue button
  if (ENABLE_6X == 1)
  {
	  MotionFX_enable_6X(mfxstate, MFX_ENGINE_ENABLE);
  }
  /* USER CODE END 2 */

  /* Infinite loop */
  /* USER CODE BEGIN WHILE */
  ssd1306_SetCursor(0,0);
  ret = ssd1306_WriteString(salutations, Font_7x10, White);
  ssd1306_UpdateScreen();
  HAL_Delay(5000);
  setMotorSpeed(right, 2500, back);
  setMotorSpeed(left, 2500, back);
  HAL_Delay(3000);
  setMotorSpeed(right, 0, back);
  setMotorSpeed(left, 0, back);
  is_cal_str = 1;
  HAL_Delay(100);
  straight_angle = str_sum / n_str;
  str_sum = 0;
  n_str = 0;
  is_cal_str = 0;
  calibrating = 0;
  HAL_Delay(2400);
  center(straight_angle);
  //moveOne(straight_angle);
  HAL_Delay(2500);
  while (1)
  {
	  // SOLVER CODE BEGIN

	  switch(floodFill()){
		  case(IDLE): {break;}
		  case(FORWARD): {moveOne(straight_angle); break;}
		  case(LEFT): {turnLeft(straight_angle); straight_angle += 90; break;}
		  case(RIGHT): {turnRight(straight_angle); straight_angle -= 90; break;}
	  }
	  if (straight_angle > 360){
		  straight_angle -= 360;
	  }
	  else if (straight_angle < -360){
		  straight_angle += 360;
	  }
	  HAL_Delay(3000);

	  // SOLVER CODE END
	  //setPIDGoals(straight_angle, 480); // move one tile

	  ssd1306_SetCursor(0,0);
	  ret = ssd1306_WriteString(empty, Font_7x10, White);
	  ssd1306_SetCursor(0,0);
	  ret = ssd1306_WriteString(xline, Font_7x10, White);
	  itoa(error, buffer, (int) 10);
	  ret = ssd1306_WriteString(buffer, Font_7x10, White);

	  ssd1306_SetCursor(0,10);
	  ret = ssd1306_WriteString(empty, Font_7x10, White);
	  ssd1306_SetCursor(0,10);
	  ret = ssd1306_WriteString(yline, Font_7x10, White);
	  itoa((getMotorEnc(right) + getMotorEnc(left))/2, buffer, (int) 10);
	  ret = ssd1306_WriteString(buffer, Font_7x10, White);

	  ssd1306_SetCursor(0,20);
	  ret = ssd1306_WriteString(empty, Font_7x10, White);
	  ssd1306_SetCursor(0,20);
	  ret = ssd1306_WriteString(zline, Font_7x10, White);
	  ftoa((mfx_data_out.rotation)[0] - straight_angle, buffer, (int) 10);
	  ret = ssd1306_WriteString(buffer, Font_7x10, White);

	  ssd1306_UpdateScreen();
	  //HAL_Delay(2500);


    /* USER CODE END WHILE */

    /* USER CODE BEGIN 3 */
  }
  /* USER CODE END 3 */
}

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
/* USER CODE BEGIN 4 */
ADC_HandleTypeDef* Get_HADC1_Ptr(void)
{
    return &hadc1;
}

void HAL_TIM_PeriodElapsedCallback(TIM_HandleTypeDef* htim){
	//debug = HAL_GetTick();
	if (htim->Instance == TIM4){
		updateGyro();
	}
	 __HAL_TIM_CLEAR_FLAG(&htim4, TIM_FLAG_UPDATE);
	//while (TIM4->SR  != 0x0);
}

void updateError(int16_t e){
	error = e;
}

void updateGyro(){
	float dT;

	CUSTOM_MOTION_SENSOR_GetAxesRaw(CUSTOM_ISM330DHCX_0, MOTION_ACCELERO, &acc_raw);

	CurrentTime = HAL_GetTick();
	dT = ((float) CurrentTime - (float) LastTime) / 1000;

	CUSTOM_MOTION_SENSOR_GetAxesRaw(CUSTOM_ISM330DHCX_0, MOTION_GYRO, &gyr_raw);

	mfx_data_in.acc[0] = (float) acc_raw.x * (ACCEL_SENSITIVITY / 1000);
	mfx_data_in.acc[1] = (float) acc_raw.y * (ACCEL_SENSITIVITY / 1000);
	mfx_data_in.acc[2] = (float) acc_raw.z * (ACCEL_SENSITIVITY / 1000);
	mfx_data_in.gyro[0] = ((float) gyr_raw.x) * (GYRO_SENSITIVITY / 1000);
	mfx_data_in.gyro[1] = (float) gyr_raw.y * (GYRO_SENSITIVITY / 1000);
	mfx_data_in.gyro[2] = (float) gyr_raw.z * (GYRO_SENSITIVITY / 1000);

	MotionFX_propagate(mfxstate, &mfx_data_out, &mfx_data_in, &dT);
	MotionFX_update(mfxstate, &mfx_data_out, &mfx_data_in, &dT, NULL);
	if (ENABLE_6X == 1)
	{
	q = mfx_data_out.rotation;
	}
	else
	{
	/* Rotation Vector in 9X */
	q = mfx_data_out.rotation;
	}
	LastTime = CurrentTime;

	if (is_cal_str){
		str_sum += (mfx_data_out.rotation)[0];
		n_str++;
	}
	if (!calibrating)
		pid((mfx_data_out.rotation)[0]);

}
char MotionAC_LoadCalFromNVM (unsigned short intdataSize, unsigned int *data){
	return 0;
}
char MotionAC_SaveCalInNVM (unsigned short intdataSize, unsigned int *data){
	return 0;
}
/* USER CODE END 4 */
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


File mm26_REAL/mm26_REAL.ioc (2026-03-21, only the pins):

Mcu.UserName=STM32L476RGTx
PA0.GPIO_Label=ENC1_A
PA0.Signal=S_TIM2_CH1
PA1.GPIO_Label=ENC1_B
PA1.Signal=S_TIM2_CH2
PA10.GPIO_Label=M1_CC
PA10.Signal=S_TIM1_CH3
PA11.GPIO_Label=M1_C
PA11.Signal=S_TIM1_CH4
PA2.GPIO_Label=USART_TX
PA2.Signal=USART2_TX
PA3.GPIO_Label=USART_RX
PA3.Signal=USART2_RX
PA4.GPIO_Label=Gyro_CS
PA4.Signal=GPIO_Output
PA5.GPIO_Label=LD2 [green Led]
PA5.Signal=GPIO_Output
PA6.GPIO_Label=ENC2_B
PA6.Signal=S_TIM3_CH1
PA7.GPIO_Label=ENC2_A
PA7.Signal=S_TIM3_CH2
PA8.GPIO_Label=M2_CC
PA8.Signal=S_TIM1_CH1
PA9.GPIO_Label=M2_C
PA9.Signal=S_TIM1_CH2
PB0.GPIO_Label=IR_IN_FRONT
PB0.Signal=ADCx_IN15
PB1.GPIO_Label=IR_IN_R
PB1.Signal=ADCx_IN16
PB12.GPIO_Label=OLED_CS
PB12.Signal=GPIO_Output
PB13.GPIO_Label=OLED_SCK
PB13.Signal=SPI2_SCK
PC10.GPIO_Label=Gyro_SCK
PC10.Signal=SPI3_SCK
PC11.GPIO_Label=Gyro_MISO
PC11.Signal=SPI3_MISO
PC12.GPIO_Label=Gyro_MOSI
PC12.Signal=SPI3_MOSI
PC13.GPIO_Label=B1 [Blue PushButton]
PC13.Signal=GPXTI13
PC2.GPIO_Label=OLED_DC
PC2.Signal=GPIO_Output
PC3.GPIO_Label=OLED_MOSI
PC3.Signal=SPI2_MOSI
PC4.GPIO_Label=IR_IN_R_DIAG
PC4.Signal=ADCx_IN13
PC5.GPIO_Label=IR_IN_LEFT
PC5.Signal=ADCx_IN14
PC8.GPIO_Label=OLED_RST
PC8.Signal=GPIO_Output

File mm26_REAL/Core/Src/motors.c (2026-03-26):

#include "motors.h"

#define SET_MLF(x) TIM1->CCR1 = x
#define SET_MLB(x) TIM1->CCR2 = x
#define SET_MRB(x) TIM1->CCR3 = x
#define SET_MRF(x) TIM1->CCR4 = x

#define GET_MR_ENC() TIM2->CNT
#define GET_ML_ENC() TIM3->CNT


#define ACCEL_THRESH 100
int16_t lastRightVal, lastLeftVal;


void setMotorEnc(motor side, int16_t encVal){
	if (side == right){
		GET_MR_ENC() = encVal;
	}
	if (side == left){
		GET_ML_ENC() = encVal;
	}
}

int16_t getMotorEnc(motor side){
	switch(side){
		case(right): {return GET_MR_ENC();}
		case(left): {return GET_ML_ENC();}
		break;
	}
	return 0;
}

void setMotorSpeed(motor side, uint16_t speed, direction dir){
	if (side == left){
		if (dir == forward){
				SET_MLB(0);
				SET_MLF(speed);
				}
		if (dir == back){
				SET_MLB(speed);
				lastLeftVal = speed;
				}
	}
	if (side == right){
		if (dir == forward){
			SET_MRB(0);
			SET_MRF(speed);
			}
			if (dir == back){
					SET_MRF(0);
					SET_MRB(speed);
				}	
	}
}

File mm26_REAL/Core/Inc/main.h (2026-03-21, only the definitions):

#define B1_Pin GPIO_PIN_13
#define B1_GPIO_Port GPIOC
#define OLED_DC_Pin GPIO_PIN_2
#define OLED_DC_GPIO_Port GPIOC
#define OLED_MOSI_Pin GPIO_PIN_3
#define OLED_MOSI_GPIO_Port GPIOC
#define ENC1_A_Pin GPIO_PIN_0
#define ENC1_A_GPIO_Port GPIOA
#define ENC1_B_Pin GPIO_PIN_1
#define ENC1_B_GPIO_Port GPIOA
#define USART_TX_Pin GPIO_PIN_2
#define USART_TX_GPIO_Port GPIOA
#define USART_RX_Pin GPIO_PIN_3
#define USART_RX_GPIO_Port GPIOA
#define Gyro_CS_Pin GPIO_PIN_4
#define Gyro_CS_GPIO_Port GPIOA
#define LD2_Pin GPIO_PIN_5
#define LD2_GPIO_Port GPIOA
#define ENC2_B_Pin GPIO_PIN_6
#define ENC2_B_GPIO_Port GPIOA
#define ENC2_A_Pin GPIO_PIN_7
#define ENC2_A_GPIO_Port GPIOA
#define IR_IN_R_DIAG_Pin GPIO_PIN_4
#define IR_IN_R_DIAG_GPIO_Port GPIOC
#define IR_IN_LEFT_Pin GPIO_PIN_5
#define IR_IN_LEFT_GPIO_Port GPIOC
#define IR_IN_FRONT_Pin GPIO_PIN_0
#define IR_IN_FRONT_GPIO_Port GPIOB
#define IR_IN_R_Pin GPIO_PIN_1
#define IR_IN_R_GPIO_Port GPIOB
#define OLED_CS_Pin GPIO_PIN_12
#define OLED_CS_GPIO_Port GPIOB
#define OLED_SCK_Pin GPIO_PIN_13
#define OLED_SCK_GPIO_Port GPIOB
#define OLED_RST_Pin GPIO_PIN_8
#define OLED_RST_GPIO_Port GPIOC
#define M2_CC_Pin GPIO_PIN_8
#define M2_CC_GPIO_Port GPIOA
#define M2_C_Pin GPIO_PIN_9
#define M2_C_GPIO_Port GPIOA
#define M1_CC_Pin GPIO_PIN_10
#define M1_CC_GPIO_Port GPIOA
#define M1_C_Pin GPIO_PIN_11
#define M1_C_GPIO_Port GPIOA
#define TMS_Pin GPIO_PIN_13
#define TMS_GPIO_Port GPIOA
#define TCK_Pin GPIO_PIN_14
#define TCK_GPIO_Port GPIOA
#define Gyro_SCK_Pin GPIO_PIN_10
#define Gyro_SCK_GPIO_Port GPIOC
#define Gyro_MISO_Pin GPIO_PIN_11
#define Gyro_MISO_GPIO_Port GPIOC
#define Gyro_MOSI_Pin GPIO_PIN_12
#define Gyro_MOSI_GPIO_Port GPIOC
#define SWO_Pin GPIO_PIN_3
#define SWO_GPIO_Port GPIOB

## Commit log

2026-01-29 created bill of parts
    [MM_26 Bill of Parts.xlsx]
2026-01-29 added kicad and voltage regulator
    [AZ1117IH-3.3TRG1.step, MM26.kicad_pcb, MM26.kicad_sch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]
2026-01-30 added oled to bom
    [MM_26 Bill of Parts.xlsx]
2026-01-30 imported MCU to KiCAD
    [MM26.kicad_sch, MM_26 Bill of Parts.xlsx]
2026-02-03 Imported Everything
    [L293DD.step, MM26.kicad_pcb, MM26.kicad_sch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]
2026-02-03 H Bridge Wiring
    [MM26.kicad_sch, MM_26 Bill of Parts.xlsx]
2026-02-04 good enough schematic
    [MM26.kicad_sch]
2026-02-11 all components placed on pcb
    just need to route it now
    [MM26.kicad_pcb, MM26.kicad_sch, MM_26 Bill of Parts.xlsx]
2026-02-12 pcb done
    [MM26-B_Cu.gbr, MM26-B_Mask.gbr, MM26-B_Paste.gbr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]
2026-02-19 cut the thing in half
    forgot to upload this earlier
    [EG1213.step, MM26.kicad_pcb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]
2026-03-10 STM32 FILES
    sorry for not pushing in eons
2026-03-10 motor code shell
2026-03-10 Set Motor Speed function Complete
2026-03-10 Encoder Method
2026-03-12 PID Beginning
2026-03-12 Encoder reset added
2026-03-12 Reset Encoder updated
2026-03-13 Encoder Rest
2026-03-17 tryna gyro
2026-03-21 theoretical
    pid tuning yaaaay

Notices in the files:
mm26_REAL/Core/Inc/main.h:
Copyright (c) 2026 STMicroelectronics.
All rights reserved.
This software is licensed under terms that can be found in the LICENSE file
